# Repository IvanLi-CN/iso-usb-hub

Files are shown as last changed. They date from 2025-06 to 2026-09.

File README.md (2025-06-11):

# Ivan's Isolated USB HUB

3C1A, isolated High Speed USB Hub.

The FreeCAD project file is located at [`models/iso-usb-hub-with-pd.FCStd`](models/iso-usb-hub-with-pd.FCStd).
Exported 3D printable models for the front and back covers are located at:

- [`models/iso-usb-hub-with-pd-Front.step`](models/iso-usb-hub-with-pd-Front.step)
- [`models/iso-usb-hub-with-pd-Back.step`](models/iso-usb-hub-with-pd-Back.step)

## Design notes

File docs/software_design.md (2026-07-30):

# 软件设计文档

本文件为项目的软件设计总文档，收录各子模块的软件规范、调度建议与统一的日志风格。新增或调整任何模块设计，须更新本文件保持单一事实来源。

## 0. 全局约定

### 0.1 全局目标状态

- 定义全局读写锁变量：`PWR_SW_TARGET`，枚举：`Open` / `Closed`。
  - 类型建议（实现细节示例，不具强制性）：`static RwLock<PowerSwitchTarget>`。
  - 语义：目标状态（意图），不等同于实际导通状态。

### 0.2 日志风格

- 统一使用分级日志（`log` → `esp-println`），单行键值对风格，便于机读与筛选。
- 模块前缀使用短名加域，如：`pwr.in`（电源输入）。
- SI 单位与后缀：电压 `V`、电流 `A` 等。
- 级别：
  - 周期/状态与条件变化：`info`；
  - 读数失败：`warn`；
  - 明显非法/越界：`error`。

### 0.3 调度与并发（embassy 建议）

- 使用 `embassy-time` 为周期任务建两个独立异步任务；共享测量数据与目标态使用 `RwLock/Mutex` 保护；
- 避免死锁：按“先读目标态、后读测量”的固定顺序获取锁。

---

## 1. 固件初始化流程（Boot Init）

说明：初始化阶段在主任务启动后、其他周期性任务（如电源输入资格/状态任务）之前一次性执行。I²C 总线为共享资源，初始化流程需串行访问，避免并发访问。

### 1.1 启动阶段与自检状态机

- 启动流程分为 `Early Bring-up -> Self-Check -> Gate Apply -> Runtime` 四阶段，由统一的 boot self-check 快照驱动。
- `Self-Check` 阶段同时承担三件事：
  - 输出 `boot.stage:*`、`boot.check:*`、`boot.summary:*` 日志；
  - 驱动 160x50 LCD 的启动自检页；
  - 产出 `GateDecision`，决定是否放行 runtime task、front panel 和各路端口。
- 统一状态口径：
  - `SelfCheckItemState = Pending / Ok / Warn / Err / Fatal / Skipped`
  - `BootOutcome = Ok / Degraded / Fatal`
  - `BootFaultCode` 覆盖 `MuxOffline`、`PowerInUnavailable`、`PowerInPgBad`、`PowerInOvervoltage`、`InaUnavailable`、`FrontPanelOffline`、`FanUnavailable` 以及按端口编号的配对/保护/超时故障。
- 默认策略是“只读探测 + 分级降级”：
  - 缺模块、单路异常优先降级；
  - 当前 V3 硬件下，front panel 离线在有限恢复失败后降级继续运行；
  - 只有输入电源不安全、或明确无法保证通道安全关闭时才进入 `Fatal`。

### 1.2 基础初始化（时钟/日志/时间源/I²C/LCD）

- 时钟与外设：调用 `esp_hal::init(esp_hal::Config::default())` 初始化外设；用 `esp_hal_embassy::init()` 绑定 `embassy-time` 时间源。
- 日志：沿用“0.2 日志风格（defmt）”；启动关键路径必须保持单行键值对输出，便于错过串口首帧时仍能从后续摘要定位问题。
- I²C：V3 使用两条 MCU I²C 控制器并分别用 `embassy_sync::Mutex` + `static_cell::StaticCell` 构建共享访问。
  - `SDA1/SCL1 = GPIO8/GPIO9`：输入 INA226、前面板、OUT3/OUT4 输出模块传感器；
  - `SDA0/SCL0 = GPIO14/GPIO13`：主板 `TCA6408A@0x20` hub-sideband、OUT1/OUT2 输出模块传感器。
- LCD：显示初始化成功后，先进入 boot self-check 页，不再把 dashboard 首帧当作“系统一定正常”的信号。
  - 当前 V3 主板由 MCU 直接驱动 `DC/MOSI/SCLK/BLK`；
  - LCD `CS/RES` 由前面板 `TCA6408A@0x21` 控制：`P6=CS` 保持输出低，`P5=RES` 启动时低脉冲后释放为输出高；
  - `GPIO13/GPIO14` 是 `SCL0/SDA0`，不得作为 LCD `CS/RST` 使用；
  - GC9D01 驱动实例使用 no-op reset pin，避免把 `GPIO35/RESET#` 误当 LCD reset 再次拉低。

初始化期建议日志（示例）：

- `app.start`
- `init.time: embassy-timer=ok`
- `boot.stage: stage=self-check`

### 1.3 自检顺序与门控顺序（强制）

boot self-check 采用固定顺序，避免不同模块各自抢总线与各说各话：

1) 完成日志、时间源、LCD、两条 I²C 与基础 GPIO 的早期 bring-up；
2) 确认当前 I²C 拓扑：
   - 当前工程验证板为直连共享总线，记录 `boot.check: name=mux state=skip fault=-`；
   - 若后续硬件版本恢复 `PCA9545A`，再切回真实 MUX 探测与门控。
3) 启动并等待基础电源输入资格结果：
   - `INA226` 初始化失败、VIN 不可用或 `PG` 不良都由 `power_in::bootstrap_signal()` 返回；
   - 若输入资格失败，`IN_CE` 必须保持关闭态（GPIO41=high，强制下拉 TPS2490 EN），runtime 与端口初始化均不放行。
4) 在 VIN ready 时探测前面板 `TCA6408A` 与风扇链路：
   - 当前 V3 硬件下，front panel 离线记为 `Warn/FrontPanelOffline`，仅关闭面板功能；
   - 风扇链路初始化失败记为 `Warn/FanUnavailable`，不阻断 dashboard。
5) 仅在 `VIN ready` 时初始化主板 CH335F sideband 与四路端口扫描：
   - 主板 `TCA6408A@0x20` 位于 `SDA0/SCL0`，负责读取 CH335F `PWREN#` 与注入 `OVCUR#`；
   - 若 `TCA6408A@0x20` 离线，runtime 进入 degraded manual mode：owner 显式开启的端口可保持输出，但 `OVCUR#` 注入不可用，控制面必须继续报告 sideband fault；
   - 每路检查 V3 输出模块金手指下挂的 `INA226/TMP112` 是否都可达；
   - 当前验证基线下，通道 4 的正式地址组合为 `INA226(0x43)` + `TMP112(0x4B)`；
   - 单路传感器失败只记录该路 `Err`，不再单独阻断该路 `ENx` 放行。
6) 汇总 `GateDecision`，输出 `boot.summary:*`：
   - `BootOutcome=Fatal`：LCD 常驻自检页；
   - `BootOutcome=Degraded`：短暂展示摘要后进入 dashboard；
   - `BootOutcome=Ok`：直接进入 runtime。

### 1.4 I²C 多路开关 PCA9545A（0x70）

- 当前工程验证板未接入 `PCA9545A`，固件按“直连共享总线”运行，并在启动日志中输出：
  - `i2c.topo: direct shared bus; mux probe skipped`
  - `boot.check: name=mux state=skip fault=-`
- 兼容策略：
  - boot self-check 快照继续保留 `mux` 槽位，用于兼容下个硬件版本恢复 `PCA9545A`；
  - 当前版本 `mux=Skipped` 不参与 fatal/degraded 判定，也不阻断端口扫描；
  - 后续若恢复 `PCA9545A`，应在本节恢复真实探测、故障码与门控要求。

### 1.5 四路输出模块发现与初始化（V3: INA226 + TMP112）

- V3 输出模块的金手指暴露 `SDA/SCL/INT/EN`，模块网表可见两颗 I2C 器件：`INA226` 与 `TMP112`。
- 当前验证基线的正式地址表：
  - 通道 1：`INA226(0x40)` + `TMP112(0x48)`
  - 通道 2：`INA226(0x41)` + `TMP112(0x49)`
  - 通道 3：`INA226(0x42)` + `TMP112(0x4A)`
  - 通道 4：`INA226(0x43)` + `TMP112(0x4B)`
- 总线分配以主板网表为准：通道 1/2 位于 `SDA0/SCL0`，通道 3/4 位于 `SDA1/SCL1`。
- 逐通道初始化策略（串行）：
  1) 在共享 I²C 上对该路地址对执行只读 ACK/寄存器探测；
  2) 两颗都在线则将通道标记为 `Ok`；
  3) 任一探测失败则将通道标记为 `Err`，但不改变“总输入 OK 后统一放行输出”的总门控策略。
- 结果与故障码约定：
  - `INA226 + TMP112` 都成功：端口记为 `Ok`，允许该路 dashboard/runtime 读取；
  - 两者都离线：`Err/PortModuleOffline(ch)`；
  - 仅 `INA226` 离线：`Err/PortInaOffline(ch)`；
  - 仅 `TMP112` 离线：`Err/PortTempOffline(ch)`。
- 安全要求：
  - 单路异常不会阻断其它通道扫描；
  - 只要总输入资格为 `OK` 且主板 CH335F sideband 在线，自检结束后按 CH335F sideband 模式与过流 latch 分别控制 `EN1..EN4`；
  - 单路 `Err` 仅影响诊断与运行期该路测量读取，不再单独关断该路输出。
  - 端口传感器缺失按 degraded 处理，不单独提升整机为 fatal。

### 1.5.1 CH335F sideband 与输出门控

- 主板 `TCA6408A@0x20` 连接 CH335F 的 `PWREN#` 与 `OVCUR#`：
  - I²C 位于 `SDA0/SCL0 = GPIO14/GPIO13`；
  - P0/P2/P4/P6：输入，读取低有效 `PWREN1#..4#`，软件语义 `0=enabled`；
  - P1/P3/P5/P7：`OVCUR1#..4#` 注入，低有效。
- MCU `GPIO21` 读取 ISOUSB211 `V1OK`，用于区分上游隔离侧电源状态：
  - `V1OK=low`：standalone/no-upstream，产品保持独立供电输出能力；
  - `V1OK=high`：upstream-managed，按 CH335F `PWREN#` 控制对应通道。
- 初始化默认释放所有 `OVCUR#`：
  - 输出寄存器 `0x01` 写 `0xFF`；
  - 极性寄存器 `0x02` 写 `0x00`；
  - 配置寄存器 `0x03` 写 `0xFF`，让 `OVCUR#` 处于输入高阻释放状态。
- 运行期每路输出使能条件：
  - `VIN ready`；
  - 主板 `TCA6408A@0x20` 在线；若离线则进入 degraded manual mode，仅按 owner 手动状态与 OCP latch 放行输出；
  - 若 `V1OK=low`，进入 standalone 模式：四路输出不因 `PWREN#` 关闭；
  - 若 `V1OK=high`，进入 upstream-managed 模式：对应 `PWREN#` 为低的通道允许输出，为高的通道关闭输出；
  - 对应软件过流 latch 未置位。
- `OVCUR#` 控制策略：
  - 释放：先写输出位为 `1`，再把对应 P 口配置为输入；
  - 注入过流：先写输出位为 `0`，再把对应 P 口配置为输出。
- 软件过流判定：
  - `vbus < 3.0 V && current > 0.1 A`；
  - 或 `current > 5.3 A`；
  - 命中任一条件立即关闭对应 `ENx` 并注入 `OVCUR#`；
  - 连续 4 个 500 ms 运行期采样周期恢复安全后释放 latch；
  - 关闭输出后采到的 0V/0mA 不作为安全恢复证据；
  - latch 后先关断，再在 sideband 模式、前面板手动状态与全局目标仍允许时进入带电恢复探测，只有带电样本连续安全才释放。

### 1.6 前面板与风扇链路

- 主板 `RESET#` 使用 `GPIO35`，低电平复位主板侧相关器件和前面板 `TCA6408A@0x21`，启动时固件先输出低电平脉冲，再以推挽高电平保持释放，并记录释放电平。
- 前面板 `TCA6408A@0x21` 在线后，固件配置 `P5/P6` 为 LCD `RES/CS` 输出；按键输入使用 `P0..P4`。
- 主板风扇供电由 `TPS62933DRLR` buck 生成 `FAN_VCC`：
  - `GPIO2/FAN_EN` 直接驱动 buck `EN`，高电平使能；
  - `GPIO1/FAN_PWM` 通过 `R15 -> VCTRL/C16 -> R18` 注入 buck `FB`；
  - `FAN_PWM` 平均电压越高，`FB` 越高，`FAN_VCC` 越低，因此固件的速度百分比到硬件 duty 为反相映射；
  - `GPIO6/FAN_TOUCH` 通过 PCNT 计数，外部 4.7 kΩ 上拉到 3V3，并有 100 pF 到地滤波。
- 硬件快照将风扇运行期状态作为调试契约输出：内部温度、过温告警、`FAN_EN` 使能、tach 可信性、实测 RPM、目标 RPM、最大 RPM、控制速度百分比与反相后的硬件 PWM duty。
- 固件初始化 I²C 外设前先释放 SDA/SCL 并输出 SCL 恢复脉冲，清理 MCU-only reset 可能留下的半截 I²C 事务。
- 前面板 `TCA6408A` 地址为 `0x21`，仅在输入电源 ready 后探测。
- 成功日志：`i2c.front: tca6408a=online addr=0x21`
- 失败日志：`i2c.front: tca6408a=offline addr=0x21; retry=N/M`
- 前面板离线诊断日志：
  - `i2c.recover:*` 记录 bus-clear 前后的 SDA/SCL 电平；
  - `i2c.front_probe:*` 记录 `0x21` 输入寄存器读取和 ACK fallback；
  - `i2c.front_diag:*` 记录 `0x21/0x20/0x44/0x70` 在线矩阵和分类。
- 门控要求：
  - 当前 V3 硬件没有 MCU 可控的前面板 TCA reset/VCCP 恢复路径；
  - 固件在初始化 I²C 前执行 bus-clear，随后有限次探测 `0x21`；
  - 若 bus-clear 后共享总线上其它器件在线但 `0x21` 仍不 ACK，当前硬件标记 `Warn/FrontPanelOffline` 并继续 dashboard/runtime，仅禁用前面板输入任务；
  - 未来硬件修订引出前面板 TCA `RESET#` 或 VCCP 控制后，应撤销当前降级路径，改为执行硬复位恢复并要求 `0x21` 在线后再进入 runtime；
  - 风扇链路初始化失败仅记录 `Warn/FanUnavailable`，不将整机提升为 fatal。
- 运行期前面板按键以 `INT` 触发读取为主，低频 fallback 轮询仅用于兜底，避免频繁占用共享 I²C 总线。

### 1.7 启动失败与异常处理约定

- 器件“不可达/不存在”优先记录为 `Warn / Err / Skipped`，不允许直接因为单个探测失败而 `panic!`；
- 输入电源资格失败时：
  - `IN_CE` 必须保持关闭态（GPIO41=high，强制下拉 TPS2490 EN）；
  - 四路端口全部 `Skipped`；
  - `GateDecision.allow_runtime_tasks=false`；
  - LCD 停留在 fatal 自检页。
  - 若 `INA226.VBUS > 28.0 V`，故障码为 `PowerInOvervoltage`，串口、LCD 与硬件快照显示 `VIN OVP`。
- 通道传感器缺失（`INA226/TMP112` 不齐）：
  - 打印 `warn`；
  - 标记对应通道 `Err`；
  - 继续扫描其它通道，并在总输入 `OK` 时保持统一放行输出。
- 统一摘要日志示例：
  - `boot.check: name=vin state=FATAL fault=PG BAD ...`
  - `boot.summary: outcome=DEG first_fault=FAN runtime=on front_panel=on`

### 1.8 运行期资源交接

- 运行期继续复用共享 async I²C；
- 只有 `GateDecision.allow_runtime_tasks=true` 时，才允许进入 dashboard 与周期刷新；
- 只有 `GateDecision.allow_front_panel=true` 时，才允许启动前面板任务；
- `BootSelfCheckSnapshot` 是日志、自检页与门控决策的单一事实来源。

### 1.8.1 前面板手动通道控制

- 前面板任务只负责读取 TCA6408A 输入并发布去抖后的按键下降沿事件，不直接持有或驱动 `EN1..EN4`。
- Dashboard 运行期维护当前选中通道，初始为通道 1；左/右方向键在 4 路输出间循环移动选中通道。
- 中键短按切换选中通道的手动输出允许状态：
  - 手动断开时，对应 `ENx` 拉低，dashboard 该列显示 `OFF`；
  - 手动恢复时，仅当总输入资格仍为 ready 时，对应 `ENx` 拉高；
  - 手动断开状态优先于 INA226/TMP112 在线状态和运行期遥测显示。
- 左/右选择变化与中键手动状态变化必须立即触发当前 dashboard 帧重绘并刷新到 LCD；周期遥测刷新不能成为前面板交互反馈的唯一显示路径。
- 手动状态不持久化；每次上电后默认四路手动允许，实际输出仍受总输入电源门控约束。

### 1.8.2 蜂鸣器音效

- V3 `BUZZER` 网络由 ESP32-S3 `GPIO7` 驱动；固件使用 LEDC 硬件 PWM 播放无源蜂鸣器音效。LEDC 外设由启动流程统一初始化，fan 使用 Timer0/Channel0，蜂鸣器使用 Timer1/Channel1，播放期间 CPU 只在音符边界调度，不生成半周期波形。
- GPIO7 空闲与每段音效播放完成后必须拉低，确保静音态稳定。
- 硬件快照输出蜂鸣器 driver ready、当前是否播放、one-shot tone、循环 alarm、频率与 duty，用于只读调试，不提供写寄存器或强制发声入口。
- 固件内置音效表来自 `tools/buzzer_audio_preview/` 试听页的推荐候选；运行时不读取 HTML、JSON、MIDI 或 WAV 试听产物。
- Boot 音：
  - boot self-check 结果非 `Fatal`，且阶段切换到 `Runtime` 后播放开机音；
  - `Fatal` 停留页不播放开机音。
- 前面板按键音：
  - Left/Right 选中通道移动成功时播放操作提示音；
  - Center 成功启用通道时播放通道上电音；
  - Center 成功禁用通道时播放通道断电音；
  - Center 尝试启用通道但因 OCP latch、全局 `PWR_SW_TARGET=Open`、CH335F sideband gate 或端口未就绪被拒绝时播放操作拒绝音，并记录拒绝原因；
  - Up/Down 当前无定义动作，保持静默。
- USB JSONL 与 network 控制面触发 `PortPowerSet(enabled=true)` 时播放通道上电音；触发 `PortPowerSet(enabled=false)` 或 `PortReplug` 时播放通道断电音。
- 告警音由运行期 reducer 选择唯一 active alarm，优先级为：
  1. `channel_short`；
  2. `over_temp`；
  3. `input_over_power`；
  4. `channel_over_5a`；
  5. one-shot 音效。
- 告警映射：
  - `channel_short` 复用现有低 VBUS OCP：`vbus < 3000mV && current > 100mA`；
  - `channel_over_5a` 在任一 active 通道的新鲜遥测 `current_ma >= 5000` 或 high-current OCP latch 时触发，按长间隔循环；
  - `over_temp` 复用 fan 安全阈值：80C 触发，75C 清除；
  - `input_over_power` 使用输入电源最新状态计算 `VIN * |I|`：100W 触发，90W 清除。
- 通道提示音使用 per-port hysteresis：
  - 插入：`vbus_mv >= 3300`；
  - 拔出：`vbus_mv < 3000`；
  - 3A 提示：首次 `current_ma >= 3000`，低于 `2800` 后复位；
  - 5A 提示：首次 `current_ma >= 5000`，低于 `4800` 后复位。
- 保护关断同一 tick 内必须抑制普通拔出/断电提示，只保留告警音。
- 可观测日志：
  - `buzzer.play: tone=<name>`；
  - `buzzer.alarm: active=<name|none>`；
  - `buzzer.alarm.play: tone=<name>`。

### 1.8.3 只读硬件底层快照

- 固件通过 Local USB JSONL `hardware.snapshot` 返回最新 `isolarail.hardware.snapshot.v1` 快照缓存；
- 快照是只读诊断接口，只汇总已有启动自检、运行期采样、I²C 探测和寄存器只读结果；
- 节点状态统一使用 `online` / `offline` / `skipped` / `error`，前面板 `TCA6408A@0x21` 与四路输出模块传感器允许离线；
- 单个节点离线只进入该节点状态与 reason，不得导致整包输出失败；
- Web 高级调试页位于 `/devices/:deviceId/debug/hardware`，作为设备路径下的 Advanced/Debug 入口，不替代主 dashboard/settings workflow；
- 详细 schema 与验收标准见 `docs/specs/n8x4q-hardware-diag-snapshot/SPEC.md`。

### 1.9 参考 crate 与接口（事实依据）

- PCA9545A：未来恢复该硬件版本时再接回 `xca9548a` / 等价驱动；当前直连共享总线版本未启用。
- TCA6408A：`port-expander`（`Tca6408a`，基于 embedded‑hal v1，阻塞接口）。
- INA226：`ina226-tp`（async 驱动，既用于输入电源链路，也用于 V3 输出模块运行期读数）。

以上 crate 均可通过 GitHub/Docs.rs 查验 API 与用法；若后续替换为 crates.io 正式版本，请在 `Cargo.toml` 中同步更新来源与版本并在变更说明中登记。

---

## 2. 基础电源输入子系统

本节定义基础电源输入子系统的软件行为、数据源、周期性任务、判定逻辑与日志格式，确保行为可重复且无二义性。

### 2.1 硬件与信号约定

- `INA226`（I2C）：读取输入母线电压/电流。
  - 电压：`VBUS`（单位：V）。
  - 电流：`CURRENT` 或由分流电阻计算（单位：A）。
- `VIN_ADC`（ESP32-S3 `GPIO4 / ADC1_CH3`）：输入电压分压采样。
  - 分压比：11:1（100kΩ+10kΩ），母线电压换算：`V_in_from_adc = VIN_ADC * 11`。
- `IN_PG`（ESP32-S3 `GPIO42`，源自 TPS2490 `PG` 引脚）：
  - 极性：高电平表示 Power-Good（良好），低电平表示非良好/故障；
  - 类型：开漏输出（需上拉）；
  - 依据：TI TPS2490 数据手册（Power Good Open-Drain Output）。
- `IN_CE`（ESP32-S3 `GPIO41`）：驱动一颗 NMOS 下拉 TPS2490 `EN`。
  - GPIO41 高：NMOS 导通，TPS2490 `EN` 被下拉，输入开关强制关闭；
  - GPIO41 低：NMOS 关断，TPS2490 `EN` 由外围网络决定，允许输入开关闭合。

### 2.2 判定与周期任务

#### 2.2.1 启动期资格判定（基于 INA226）

> 开发阶段特别说明（当前分支生效）：
>
> - 为便于在实验室以 5V 台式电源/USB 供电对风扇等功能做独立验证，固件将 VIN 下限阈值临时放宽为 **4.5 V**（`VIN_MIN_V=4.5`）。
> - 该设置会绕过原本的欠压防护，可能导致在 5–8 V 区间触发上电流程。仅限开发/联调使用，量产前请恢复到 **9.0 V** 并完成回归验证。

- 触发条件：上电启动阶段、闭合输入开关之前执行，短暂重试（~5 次，20 ms 间隔）。
- 计算：
  - 生产阈值（规范）：`9.0 V ≤ INA226.VBUS ≤ 28.0 V`；
  - 当前固件（开发分支）：`4.5 V ≤ INA226.VBUS ≤ 28.0 V`；
- `current_ok`：`|INA226.CURRENT| ≤ 30 mA`；
  - `ok_to_close = range_ok && current_ok`。
- 日志：每次读取打印一行 `info`：`pwr.in:qual vbus=..V i=..A range_ok= current_ok=`。
- 成功后：拉低 `IN_CE` 允许输入开关闭合，并将本次 `VBUS/CURRENT` 写入共享测量，避免状态上报出现 `vin=n/a`。
- `VIN_ADC` 不参与资格判定；仅在 `PG` 超时（100 ms）时单次读取用于诊断。

#### 2.2.2 10 s 状态汇报

- 周期：`10 s`，无条件输出一行状态：
  - 字段：
    - `vin`（INA226.VBUS, V）
    - `i`（INA226.CURRENT, A）
    - `sw_intent`（on/off，来自 `PWR_SW_TARGET`，表示期望状态）
    - `sw_actual`（on/off，由 `IN_PG` 推导：PG=good→on，PG=bad→off）
    - `pg`（good/bad，由 IN_PG）
    - `note`（可空）
- 判定：
  - `pg`：IN_PG 高为 `good`，低为 `bad`；
  - 异常：若 `PWR_SW_TARGET == Closed` 且 `pg == good`，但 `V_in_from_adc` 明显低于 `INA226.VBUS`，追加 `note` 告警：
    - 比值阈值：`V_in_from_adc / INA226.VBUS < 0.60`；
    - 或差值阈值：`INA226.VBUS - V_in_from_adc > 3.0 V`；
    - 示例：`note="anom: vin_adc<<ina_v (adc=4.2V, ina=12.1V)"`。
- 示例：`pwr.in:stat vin=12.1V i=0.46A sw_intent=on sw_actual=on pg=good`。

### 2.3 边界与错误处理

- `INA226`/`VIN_ADC` 读数失败：本周期忽略数值、输出一次 `warn`，维持上次有效判定；
- 越界保护：启动资格及每个 `100 ms` 运行期保护采样中，若 `INA226.VBUS > 28.0 V`，视为输入过压，在下一保护采样周期内保持输入开关关闭并报告 `VIN OVP`；运行期过压会锁存输入关闭，直至重启或显式恢复策略。

### 2.4 精度与阈值

- 生产电压范围阈值：9.0 V 与 28.0 V；
- 开发阶段（当前分支）临时阈值：`VIN_MIN_V = 4.5 V`（为 5V 台架测试放宽）；
- 当前 V3 板启动资格电流阈值：`I_IDLE_MAX_A = 30 mA`；
  - 依据：当前 V3 基线板在 `IN_EN` 闭合前的实测空载电流约为 `22–23 mA`；
  - 旧的 `10 mA` 假设会把当前板误判成 `VIN OFF/FATAL`，导致 runtime 和 USB JSONL 永远不启动；
  - `VIN_ADC` 判定阈值固定为 2.0 V（ADC 端）；
  - 异常比值/差值阈值如上；修改阈值须同步更新本文档。

### 2.5 调度与并发（实现建议）

- `InputQualificationTask`（100 ms）与 `InputStatusTask`（10 s）两个异步任务；
- 数据共享用 `RwLock/Mutex`；获取顺序：目标态 → 测量值。

### 2.6 观测与验证要点

- 目标从 `Open→Closed` 且电压合规、`VIN_ADC < 2.0 V`，应出现一次 `ok_to_close=true` 的变化日志；
- 正常供电下，每 10 s 一行状态，`pg=good`、`ocp=false`；
- 保护/异常时，`pg=bad` 或 `note` 告警出现。

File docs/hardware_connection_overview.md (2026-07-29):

# 硬件连接概览（IsolaRail V3）

本文件汇总当前 `isolarail` V3 基线板的关键硬件连接关系，作为 README、控制面 spec 与软件设计文档之间共享的 current truth。owner-facing 设备模型固定为四路 `port1..port4`；历史 V2 `SC8815 + SW2303` / `PSTOP*` 方案不再作为本文件事实源。

## 适用范围

- 当前软件落地基线：`ESP32-S3 + CH335F + M24C64@0x50 + EN1..EN4 + PWREN#/OVCUR# + 160x50 LCD + front panel`
- 端口模型：`Port 1`、`Port 2`、`Port 3`、`Port 4`
- 当前控制面维护动作：
  - `port.replug` = 受控断电再上电
  - `hub.reset` = 整机维护复位动作

## 总体结构

- 主控：`ESP32-S3`
- USB Hub 控制器：`CH335F`
- Wi-Fi / 网络配置 EEPROM：`M24C64@0x50`
- 输入电源热插拔 / 保护：`TPS2490`
- 输入电源监测：`Input INA226@0x44`
- 主板 sideband expander：`Mainboard TCA6408A@0x20`
- 前面板 / LCD 控制 expander：`Front-panel TCA6408A@0x21`
- 预留 / 兼容命名槽位：`PCA9545A@0x70`

## 电源输入（VIN_UNSAFE → VIN）

- 直流输入网络名：`VIN_UNSAFE`
- 主系统母线：`VIN`
- 输入路径：`VIN_UNSAFE -> 5 mΩ shunt -> TPS2490 / 输入开关 -> VIN`
- 整机额定输入电压上限：`28 V`；输入 TVS 必须安装反向截止电压为 `28–30 V` 的器件。
- 关键控制/观测网络：
  - `IN_EN`：MCU 控制输入开关资格
  - `IN_PG`：高电平表示 power-good
  - `VIN_ADC`：MCU ADC 分压采样点
- 输入电源测量器件：
  - `Input INA226@0x44`：输入电压 / 电流 / 功率观测

## 四路输出与端口门控

- 四路 owner-facing 端口由 `EN1..EN4` 门控：
  - `EN1 -> Port 1`
  - `EN2 -> Port 2`
  - `EN3 -> Port 3`
  - `EN4 -> Port 4`
- 当前实现里 MCU 直驱的四路 enable GPIO 为：
  - `EN1 = GPIO17`
  - `EN2 = GPIO18`
  - `EN3 = GPIO39`
  - `EN4 = GPIO40`
- 当前 V3 板的软件语义：
  - `port.power_set` 直接影响对应 `ENx`
  - `port.replug` 通过临时拉低再恢复对应 `ENx` 实现
  - 不承诺真 per-port data disconnect

## CH335F sideband 与上游联动

- `CH335F` 的 sideband 通过 `Mainboard TCA6408A@0x20` 连接到 MCU
- 低有效输入：
  - `PWREN1#`
  - `PWREN2#`
  - `PWREN3#`
  - `PWREN4#`
- 低有效注入：
  - `OVCUR1#`
  - `OVCUR2#`
  - `OVCUR3#`
  - `OVCUR4#`
- 上游隔离状态：
  - `ISOUSB211 V1OK` 为 owner-facing 运行时状态
  - 板级网络名：`ISO_OK`
- `V1OK=low` 时，设备按 standalone/no-upstream 处理
- `V1OK=high` 时，设备按 upstream-managed 模式读取 `PWREN#`

## 两条 I²C 总线

### Sensor / front-panel I²C

- `I2C_SDA = GPIO8`
- `I2C_SCL = GPIO9`
- 当前挂载：
  - `Input INA226@0x44`
  - `Front-panel TCA6408A@0x21`
  - `Port 3 INA226@0x42 + TMP112@0x4A`
  - `Port 4 INA226@0x43 + TMP112@0x4B`

### Hub-sideband / output I²C

- `HUB_SDA = GPIO14`
- `HUB_SCL = GPIO13`
- 当前挂载：
  - `Mainboard TCA6408A@0x20`
  - `Port 1 INA226@0x40 + TMP112@0x48`
  - `Port 2 INA226@0x41 + TMP112@0x49`
  - `M24C64@0x50`

## EEPROM 与 Wi-Fi provisioning

- 配置 EEPROM：`M24C64@0x50`
- 当前固件通过板级路由信号访问该 EEPROM：
  - `ROM_WC = GPIO37`，运行期保持 low 允许写入
  - `ROM_ROUTE = GPIO38`，当前固件设为 high 选择 firmware/EERPOM 路径
- 用途：
  - 保存 Wi-Fi SSID / PSK 与网络配置
  - 作为 USB / LAN / companion / web 统一消费的设备持久化入口

## 每路端口遥测地址

- `Port 1`：`INA226@0x40` + `TMP112@0x48`
- `Port 2`：`INA226@0x41` + `TMP112@0x49`
- `Port 3`：`INA226@0x42` + `TMP112@0x4A`
- `Port 4`：`INA226@0x43` + `TMP112@0x4B`

这些地址用于运行期电压/电流/功率/温度观测，不改变 owner-facing 四路端口语义。

## 前面板与显示

- 前面板 expander：`Front-panel TCA6408A@0x21`
- 五向开关：
  - `P0 = Center`
  - `P1 = Right`
  - `P2 = Down`
  - `P3 = Left`
  - `P4 = Up`
- LCD 控制：
  - `P5 = LCD_RES`
  - `P6 = LCD_CS`
- LCD 直连 MCU 的 SPI / 控制网络：
  - `LCD_DC = GPIO10`
  - `LCD_MOSI = GPIO11`
  - `LCD_SCLK = GPIO12`
  - `LCD_BLK = GPIO15`
- 显示模块：`160x50 LCD`
- 驱动 IC：`GC9D01`
- 背光 `LCD_BLK` 当前为低有效

## Reset / 中断 / 其他板级网络

- `Mainboard RESET# = GPIO35`
- `I2C_INT`：共享 I²C 外设中断汇总输入
- `HUB_RESET#`：CH335F 复位控制网络
- `USB D+` / `USB D-`：ESP32-S3 原生 USB 差分对
- `BUZZER`：蜂鸣器控制网络
- `FAN_PWM` / `FAN_EN` / `FAN_TACH`：风扇控制与反馈网络

## 当前 V3 与历史 V2 的边界

- 本文件只描述当前 V3 current truth
- 下列术语只允许出现在历史/迁移语境，不再代表当前控制面硬件：
  - `SC8815 + SW2303`
  - `PSTOP_CTL1..4`
  - `PSTOP1..4`
  - 历史 `USB-C route` / 双口产品抽象
- `PCA9545A@0x70` 在当前文档中只作为兼容命名槽位保留；当前软件运行基线不是依赖它完成端口寻址

## 简化拓扑示意

```text
DC IN
  └─ VIN_UNSAFE -> shunt -> TPS2490 / input gate -> VIN
                      └─ Input INA226@0x44

ESP32-S3
  ├─ Sensor I2C (GPIO8/GPIO9)
  │   ├─ Front-panel TCA6408A@0x21
  │   ├─ Input INA226@0x44
  │   ├─ Port 3 INA226@0x42 + TMP112@0x4A
  │   └─ Port 4 INA226@0x43 + TMP112@0x4B
  ├─ Hub I2C (GPIO14/GPIO13)
  │   ├─ Mainboard TCA6408A@0x20
  │   ├─ M24C64@0x50
  │   ├─ Port 1 INA226@0x40 + TMP112@0x48
  │   └─ Port 2 INA226@0x41 + TMP112@0x49
  ├─ EN1..EN4 -> Port 1..4 power gate
  ├─ ISO_OK / V1OK <- upstream isolation status
  ├─ USB D+ / D- <-> native USB
  └─ LCD + front panel + buzzer + fan

CH335F
  ├─ PWREN1#..4# -> Mainboard TCA6408A@0x20 -> MCU
  └─ OVCUR1#..4# <- Mainboard TCA6408A@0x20 <- MCU
```

## 参考

- `docs/specs/pw97u-control-plane-alignment/SPEC.md`
- `docs/specs/j6nvw-hardware-v3-pin-assignment/SPEC.md`
- `docs/software_design.md`

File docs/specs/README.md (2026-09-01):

# 规格（Spec）总览

本目录用于管理工作项的**规格与追踪**：记录范围、验收标准、任务清单与状态，作为交付依据；实现与验证应以对应 `SPEC.md` 为准。

当前仓库的软件与硬件命名真相源由 `pw97u-control-plane-alignment/SPEC.md` 统一定义：

- 固件 package / identity：`isolarail`
- repo JS tooling package：`isolarail-dev-tools`
- CLI：`isolarail`
- daemon：`isolarail-devd`
- companion workspace：`tools/isolarail-companion/`
- internal support crates / tools：`gc9d01`、`dashboard_preview`、`icon2raw`、`png2raw`
- vendored example packages：`gc9d01/examples/**` 下的示例包名仅用于驱动示例，不得进入本项目 owner-facing 命名
- 开发者入口：`just`
- owner-facing 端口模型：`port1..port4`
- 当前硬件基线：`V3`
- 主控与关键子系统名：`ESP32-S3`、`CH335F`、`M24C64@0x50`、`TPS2490`、`ISOUSB211 V1OK`、`PCA9545A@0x70`、`Mainboard TCA6408A@0x20`、`Front-panel TCA6408A@0x21`
- legacy/scoped hardware names：`SC8815 + SW2303`、`PSTOP_CTL/PSTOP`、`VIN_ADC`、`PCA9545A INT/INTx`、scoped `RESET#` 只允许在硬件拓扑或迁移语境下出现
- 参考硬件资料中的 `TPS82130SILR`、`RT9043GB`、`TCA6408APWR`、`TCA6408ARSVR`、`TCA9535RTWR` 等料号仅允许作为 reference-only 历史输入，不得覆盖当前 V3 控制面命名

后续 spec、README、实现与 UI 文案不得偏离这套命名；BOM/netlist 精确料号只能作为电气资料别名，不能替代控制面 canonical 名称。

> Legacy compatibility: historical repos may still contain `docs/plan/**/PLAN.md`. New entries must be created under `docs/specs/**/SPEC.md`.

## 快速新增一个规格

1. 生成一个新的规格 `ID`（推荐 5 个字符的 nanoId 风格，降低并行建规格时的冲突概率）。
2. 新建目录：`docs/specs/<id>-<title>/`（`<title>` 用简短 slug，建议 kebab-case）。
3. 在该目录下创建 `SPEC.md`（模板见下方“SPEC.md 写法（简要）”）。
4. 在下方 Index 表新增一行，并把 `Status` 设为 `待设计` 或 `待实现`（取决于是否已冻结验收标准），并填入 `Last`（通常为当天）。

## 目录与命名规则

- 每个规格一个目录：`docs/specs/<id>-<title>/`
- `<id>`：推荐 5 个字符的 nanoId 风格，一经分配不要变更。
  - 推荐字符集（小写 + 避免易混淆字符）：`23456789abcdefghjkmnpqrstuvwxyz`
  - 正则：`[23456789abcdefghjkmnpqrstuvwxyz]{5}`
  - 兼容：若仓库历史已使用四位数字 `0001`-`9999`，允许继续共存。
- `<title>`：短标题 slug（建议 kebab-case，避免空格与特殊字符）；目录名尽量稳定。
- 人类可读标题写在 Index 的 `Title` 列；标题变更优先改 `Title`，不强制改目录名。

## 状态（Status）说明

仅允许使用以下状态值：

- `待设计`：范围/约束/验收标准尚未冻结，仍在补齐信息与决策。
- `待实现`：规格已冻结，可开工；实现与测试验证应以该规格为准。
- `跳过`：计划已冻结或部分完成，但**当前明确不应自动开工**（例如需要特定时机/外部条件/等待依赖）；自动挑选“下一个规格”时应跳过它。需要实现时再把状态改回 `待实现`（或由主人显式点名实现该规格）。
- `部分完成（x/y）`：实现进行中；`y` 为该规格里定义的“实现里程碑”数，`x` 为已完成“实现里程碑”数（见该规格 `SPEC.md` 的 Milestones；不要把计划阶段产出算进里程碑）。
- `已完成`：该规格已完成（实现已落地或将随某个 PR 落地）；如需关联 PR 号，写在 Index 的 `Notes`（例如 `PR #123`）。
- `作废`：不再推进（取消/价值不足/外部条件变化）。
- `重新设计（#<id>）`：该规格被另一个规格取代；`#<id>` 指向新的规格编号。

## `Last` 字段约定（推进时间）

- `Last` 表示该规格**上一次“推进进度/口径”**的日期，用于快速发现长期未推进的规格。
- 仅在以下情况更新 `Last`（不要因为改措辞/排版就更新）：
  - `Status` 变化（例如 `待设计` -> `待实现`，或 `部分完成（x/y）` -> `已完成`）
  - `Notes` 中写入/更新 PR 号（例如 `PR #123`）
  - `SPEC.md` 的里程碑勾选变化
  - 范围/验收标准冻结或发生实质变更

## SPEC.md 写法（简要）

每个规格的 `SPEC.md` 至少应包含：

- 背景/问题陈述（为什么要做）
- 目标 / 非目标（做什么、不做什么）
- 范围（in/out）
- 需求列表（MUST/SHOULD/COULD）
- 功能与行为规格（Functional/Behavior Spec：核心流程/关键边界/错误反馈）
- 验收标准（Given/When/Then + 边界/异常）
- 实现前置条件（Definition of Ready / Preconditions；未满足则保持 `待设计`）
- 非功能性验收/质量门槛（测试策略、质量检查、Storybook/视觉回归等按仓库已有约定）
- 文档更新（需要同步更新的项目设计文档/架构说明/README/ADR）
- 实现里程碑（Milestones，用于驱动 `部分完成（x/y）`；只写实现交付物，不要包含计划阶段产出）
- 风险与开放问题（需要决策的点）
- 假设（需主人确认）

## Index（固定表格）

<!-- markdownlint-disable MD060 -->
| ID | Title | Status | Spec | Last | Notes  |
|---:|---|---|---|---|---|
| k3p8m | 示例：新增工作项规格 | 待设计 | `k3p8m-example-spec/SPEC.md` | YYYY-MM-DD | - |
| pw97u | 四路 USB Hub 控制面对齐 | 已完成 | `pw97u-control-plane-alignment/SPEC.md` | 2026-06-29 | 当前 HEAD 已完成本地 `PR-ready` 收口：Wi-Fi/LAN、USB CDC、companion、web、current-truth 文档与视觉证据已统一对齐 |
| 5f74j | 固件健壮化与开机自检 | 已完成 | `5f74j-firmware-boot-self-check/SPEC.md` | 2026-03-17 | 当前板型为直连 I2C；保留 mux 槽位以兼容后续 PCA9545A |
| j6nvw | 硬件 V3 引脚与显示链路对齐 | 部分完成（2/3） | `j6nvw-hardware-v3-pin-assignment/SPEC.md` | 2026-04-27 | legacy `docs/plan/j6nvw-hw-v3-pin-assignment/**` 删除待确认 |
| h8c4s | CH335F sideband 电源控制 | 部分完成（2/3） | `h8c4s-ch335f-sideband-power-control/SPEC.md` | 2026-06-13 | 固件与上游侧 p1/p3/p4 控制已验证；命名已对齐到 `isolarail` / 上游侧语义；PWREN1#/2# 硬件缺陷见 issue #18 |
| 7gf6b | 固件蜂鸣器音效 | 已完成 | `7gf6b-firmware-buzzer-audio/SPEC.md` | 2026-07-05 | PR #25 |
| e5nyr | 发布失败 Telegram 告警接入 | 已完成 | `e5nyr-release-failure-telegram-alerts/SPEC.md` | 2026-09-01 | 发布/部署失败与手动 smoke 已迁移到 Oidrune `notify.yml@e48822f99c6402a753ed86557ea029754cbab20b`；GitHub Pages settings 仍需 owner 侧启用 Actions source |
| q9d7h | CLI/devd 烧录迁移 | 部分完成（3/4） | `q9d7h-cli-devd-flash-migration/SPEC.md` | 2026-07-04 | source workflow 已完成，旧烧录入口已退役；真机 flash-monitor 验证待硬件确认 |
| r6wfr | 文档 Web 站点 | 已实现 / 待外部切流 | `r6wfr-docs-site/SPEC.md` | 2026-07-05 | Rspress/Bun 双语 docs-site，`web/` 根站点 + `/docs/` 子站点组合发布到 EdgeOne / GitHub Pages |
| n8x4q | 硬件底层详细信息快照接口 | 部分完成（4/5） | `n8x4q-hardware-diag-snapshot/SPEC.md` | 2026-07-05 | 真机串口端到端验证待硬件接入 |
| b8r3n | 品牌视觉资产 | 已完成 | `b8r3n-brand-visual-assets/SPEC.md` | 2026-07-08 | PR #32；Logo、App Icon、海报、GitHub Social preview 主图与变体、HTML 海报素材 |
<!-- markdownlint-enable MD060 -->

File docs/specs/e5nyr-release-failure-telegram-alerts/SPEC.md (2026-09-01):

# 发布失败 Telegram 告警接入

## Context and Scope

仓库通过 `.github/workflows/notify-release-failure.yml` 为 `Release`、`Development Release` 与 `Site Publish` 提供发布/部署失败告警，并保留 repo-local 的手动 smoke test 入口。

本主题只定义 notifier sidecar 与 Oidrune reusable workflow 的调用契约，不改动发布逻辑、版本策略或产物内容，也不新增第二套通知渠道。调用目标固定为 `IvanLi-CN/oidrune/.github/workflows/notify.yml@e48822f99c6402a753ed86557ea029754cbab20b`，由调用方提供 OIDC 权限和完整 summary。

失败通知覆盖 `Release`、`Development Release` 以及非 PR 的 `Site Publish`；普通 PR CI 不在通知范围内。手动 `workflow_dispatch` 仅用于发送 smoke summary，本地与 PR 验证不得触发真实通知。

## Requirements

### REQ-E5NYR-001: Failure event scope

The notifier MUST listen for completed `Release`, `Development Release`, and `Site Publish` workflow runs, and MUST notify only when the conclusion is `failure`. It MUST exclude `Site Publish` runs whose event is `pull_request`.

### REQ-E5NYR-002: Pinned Oidrune target

Both notification jobs MUST call `IvanLi-CN/oidrune/.github/workflows/notify.yml@e48822f99c6402a753ed86557ea029754cbab20b`. No reusable workflow call may use `@main`.

### REQ-E5NYR-003: OIDC permission

The caller MUST provide `id-token: write` permission to the reusable workflow jobs.

### REQ-E5NYR-004: Default gateway boundary

The caller MUST omit `gateway_url` and `oidc_audience` so the pinned Oidrune workflow uses its default gateway and audience. The caller MUST NOT pass the legacy `SHOUTRRR_URL` secret or any other Telegram secret.

### REQ-E5NYR-005: Complete failure summary

The failure path MUST pass `outcome: failure` and a caller-generated summary containing a failure title, project name, status/result, target SHA, run URL, workflow, ref, attempt, actor, and event. `Site Publish` failures MUST retain deployment-specific title and note semantics.

### REQ-E5NYR-006: Manual smoke path

The `workflow_dispatch` path MUST run only the smoke job and MUST pass `outcome: failure` with a caller-generated summary titled `IsolaRail notifier smoke test`. The summary MUST include the project name, smoke status/result, current SHA, run URL, workflow, ref, attempt, actor, and event.

### REQ-E5NYR-007: Contract coverage

The repository MUST provide a repeatable workflow contract test covering the pinned target, legacy target/secret removal, OIDC permission, summary fields, failure filter, ordinary PR exclusion, and manual smoke path.

## Verification

### VER-E5NYR-001: Static workflow contract

- Method: `actionlint` and the workflow contract test cover: `REQ-E5NYR-001`, `REQ-E5NYR-002`, `REQ-E5NYR-003`, `REQ-E5NYR-004`, `REQ-E5NYR-005`, `REQ-E5NYR-006`, `REQ-E5NYR-007`.

### VER-E5NYR-002: Documentation contract

- Method: the shared Spec drift gate and markdownlint cover: `REQ-E5NYR-002`, `REQ-E5NYR-003`, `REQ-E5NYR-004`, `REQ-E5NYR-005`, `REQ-E5NYR-006`.

### VER-E5NYR-003: Repository validation

- Method: repository `cargo check` and `cargo build --release` cover: `REQ-E5NYR-001`, `REQ-E5NYR-007`.

### VER-E5NYR-004: Delivery safety

- Method: PR CI freshness and manual inspection confirm that no `workflow_dispatch` smoke run, real Telegram/Oidrune notification, or Oidrune control-plane change is performed during migration; covers: `REQ-E5NYR-004`, `REQ-E5NYR-006`.

## Related ADRs

None

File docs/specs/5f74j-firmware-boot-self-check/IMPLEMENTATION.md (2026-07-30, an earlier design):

# 固件健壮化与开机自检实现状态

## 当前状态

- Boot self-check 状态模型、阶段日志、LCD 自检页和 runtime 门控已经落地。
- 当前直连 I2C 板型保留 `mux` 槽位，但不再依赖 `PCA9545A`。
- 输入电源不安全仍是 fatal；单路端口传感器异常按 degraded 记录。
- 输入资格上限为 `28.0 V`；高于上限的输入以 `PowerInOvervoltage` / `VIN OVP` 作为可见 fatal 诊断。运行期每 `100 ms` 采样到过压时，输入开关关闭会锁存，并同步发布 `vin_on=false`。
- 当前 V3 硬件下，前面板 `TCA6408A@0x21` 离线会在有限恢复失败后降级继续运行，仅禁用前面板按键任务。
- 前面板离线时，启动日志会输出 I2C bus-clear 电平、`0x21` 分阶段探测、peer device 在线矩阵和故障分类，便于区分 MCU-only reset 后的 TCA 未复位、总线卡住和共享供电/I2C 异常。

## Coverage

- 固件：`src/main.rs` boot self-check flow、gate decision、front-panel degraded path。
- 固件：`src/boot_diag.rs` 自检状态、故障码与快照模型。
- 固件：`src/power_in.rs` 输入电源启动探测。
- 固件：`src/power_limits.rs` 输入电压范围判定与主机回归测试。
- 文档：`docs/software_design.md` 与本 spec 记录当前启动口径。

## Remaining Gaps

- 当前 V3 前面板 TCA 无 MCU 可控 `RESET#` 或 VCCP power-cycle，固件无法在 MCU-only reset 后硬复位该器件。
- 真机 MCU reset 复现中，SDA/SCL 恢复后均为 high，主板 TCA `0x20` 与输入 INA226 `0x44` 在线，前面板 TCA `0x21` 连续 NACK；当前诊断分类为 `front_tca_only_offline`。
- 未来硬件修订提供前面板 TCA reset/power-cycle 后，应移除 `blocked_no_reset_pin` 降级路径，并重新要求前面板在线后进入 runtime。

## Related Changes

- `src/main.rs`
- `src/front_panel.rs`
- `src/boot_diag.rs`
- `src/power_in.rs`
- `docs/software_design.md`

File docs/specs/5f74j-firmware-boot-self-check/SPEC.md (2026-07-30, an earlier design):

# 固件健壮化与开机自检（#5f74j）

## 状态

- Status: 已完成
- Created: 2026-03-14
- Last: 2026-03-17

## 背景 / 问题陈述

- 当前固件在关键启动探测失败时会直接 `panic!`，例如 `PCA9545A` 不在线时会在启动早期崩溃，导致后续诊断信息丢失。
- 项目需要像 `mains-aegis` 一样，把启动失败转化为可见、可定位、可门控的自检结果，而不是“黑屏 + 无日志”。
- 不做本改造的代价是：真机联调时缺少稳定的故障定位界面，串口监视窗口稍晚接入就会丢掉启动瞬间证据。

## 目标 / 非目标

### Goals

- 将启动过程重构为 `Early Bring-up -> Self-Check -> Gate Apply -> Runtime` 四阶段。
- 引入统一的 boot self-check 状态模型、故障码、门控决策和摘要页口径。
- 缺模块时优先降级继续运行；只有输入电源不安全、无法保证端口关闭、或明确保护粘滞时才进入 fatal 停留态。
- 在 160x50 LCD 上显示最小自检摘要页，并在 degraded/fatal 场景保留可复查的结果。

### Non-goals

- 不实现 `mains-aegis` 的多页面自检 UI、音频 cue、BMS 交互或复杂激活流程。
- 不改硬件地址、原理图、本机联调侧 `isolarail` monitor 产品化体验。

## 范围（Scope）

### In scope

- `src/main.rs` 启动状态机、boot self-check UI、自检日志前缀、门控策略。
- `src/power_in.rs` 启动电源探测改成“上报结果而不是 panic”。
- `src/boot_diag.rs` 新增统一状态模型。
- `docs/software_design.md` 同步新的开机自检与降级口径。

### Out of scope

- 新增额外板级硬件 kill 信号支持。
- 新的远程诊断工具或 PC 端 UI。

## 需求（Requirements）

### MUST

- 启动期关键检查必须输出 `boot.stage:*`、`boot.check:*`、`boot.summary:*` 日志。
- 输入电源链路异常时必须保持 `IN_EN` 关闭，并停留在 fatal 自检页。
- 输入资格仅接受 `INA226.VBUS ≤ 28.0 V`；超过上限时必须报告 `PowerInOvervoltage` / `VIN OVP`，并保持 `IN_EN` 关闭。
- 运行期每个 `100 ms` 保护采样必须重新判定该上限；若 `INA226.VBUS > 28.0 V`，必须在下一保护采样周期内关闭并锁存 `IN_EN`，同时发布 `vin_on=false`，不得自动重开。
- 当前 V3 硬件下，前面板缺失时必须在有限恢复失败后标记 `Warn/FrontPanelOffline`，禁用前面板输入任务，并继续进入 dashboard/runtime。
- 当前直连 I²C 板型下，端口自检失败只记录诊断，不得单独阻断该路输出；只要总输入 `OK`，自检完成后统一放行 `EN1..EN4`。
- boot self-check 必须保留 `mux` 槽位，以兼容后续硬件版本恢复 `PCA9545A`。

### SHOULD

- 自检页在启动中显示进度，并在 degraded 场景展示失败摘要后再进入 dashboard。
- 自检页的系统面和端口面使用同一套状态/故障码口径。

### COULD

- 后续将 boot self-check 快照扩展为 runtime overlay 或更丰富的维护页。

## 功能与行为规格（Functional/Behavior Spec）

### Core flows

- 固件初始化时先建立显示与基础 GPIO，再进入 `Self-Check` 阶段。
- `Self-Check` 固定顺序为：I²C 拓扑 -> VIN/INA226 -> Front Panel -> Fan -> 4 路端口。
- 通过 `GateDecision` 决定是否放行 runtime task、front panel 和各端口。
- `BootOutcome=Fatal` 时常驻自检页；`BootOutcome=Degraded` 时展示摘要后进入 dashboard；`BootOutcome=Ok` 时直接切换 dashboard。

### Edge cases / errors

- 当前板型无 `PCA9545A`：记录 `boot.check: name=mux state=skip fault=-`，端口扫描继续进行。
- VIN 不可用或 PG 不良：标记系统项 `Fatal`，不进入端口初始化，不放行 runtime。
- `INA226.VBUS > 28.0 V`：标记系统项 `Fatal/PowerInOvervoltage`，启动日志、LCD 与硬件快照使用 `VIN OVP`，不放行 runtime。
- Front panel 离线：当前 V3 硬件下标记 `Warn/FrontPanelOffline`，只禁用 panel 功能。
- Front panel 离线诊断：固件必须记录 bus-clear 前后 SDA/SCL 电平、`0x21` 输入寄存器读取结果、ACK fallback、`front INT` 电平，以及 `0x20/0x44/0x70` peer device 在线矩阵。
- 单路端口若 `INA226`/`TMP112` 缺失：标记对应端口 `Err`，但只影响诊断与该路运行期测量，不阻断统一输出放行。
- 端口自检以“存在性与可诊断性优先”为准，不再依赖旧的 `SC8815/SW2303` 初始化链路。

## 接口契约（Interfaces & Contracts）

### 接口清单（Inventory）

| 接口（Name） | 类型（Kind） | 范围（Scope） | 变更（Change） | 契约文档（Contract Doc） | 负责人（Owner） | 使用方（Consumers） | 备注（Notes） |
| --- | --- | --- | --- | --- | --- | --- | --- |
| `boot_diag` 状态模型 | internal | internal | New | None (this SPEC) | firmware | boot flow / LCD boot page | 新增内部状态与门控口径 |
| `power_in::bootstrap_signal()` | internal | internal | New | None (this SPEC) | firmware | boot flow | 提供启动期电源探测结果 |

### 契约文档（按 Kind 拆分）

None

## 验收标准（Acceptance Criteria）

- Given 板子正常上电，When 固件启动，Then LCD 先显示自检页，串口输出 `boot.stage:*` 与 `boot.check:*`，最终输出 `boot.summary: outcome=OK|DEG` 并进入 dashboard。
- Given 当前直连 I²C 板型，When 固件启动，Then 日志记录 `boot.check: name=mux state=skip fault=-`，且端口扫描继续进行。
- Given 前面板 `TCA6408A` 缺失，When 当前 V3 硬件启动，Then 固件标记 `Warn/FrontPanelOffline`，禁用前面板输入任务，并继续进入 dashboard 与 runtime。
- Given MCU-only reset 后 `TCA6408A@0x21` 不响应，When front panel 自检失败，Then 日志包含 `i2c.front_probe:*`、`i2c.front_diag:*` 和分类结果，可区分 bus stuck、front TCA only offline、shared I2C offline or power。
- Given 单路输出模块缺少 `INA226` 或 `TMP112`，When 固件启动且总输入 `OK`，Then 该路记为 `Err`，但 `EN1..EN4` 仍在自检结束后统一放行。
- Given 输入电源资格失败或 PG 不良，When 固件启动，Then `IN_EN` 保持关闭且 LCD 常驻 fatal 自检页。
- Given `INA226.VBUS` 高于 `28.0 V`，When 固件启动，Then `IN_EN` 保持关闭，且启动日志、LCD 与硬件快照报告 `VIN OVP`。
- Given 输入已合规启动，When 运行期采样到 `INA226.VBUS > 28.0 V`，Then `IN_EN` 在 `100 ms` 内关闭并保持关闭、`vin_on=false`，硬件快照报告 `VIN OVP`。
- Given 当前验证基线中的通道 4 模块接入，When 固件启动，Then 端口 4 按 `INA226@0x43 + TMP112@0x4B` 识别并可报告 `boot.check: name=port4 state=ok fault=-`。

## 实现前置条件（Definition of Ready / Preconditions）

- 目标、非目标、范围与 fatal/degraded 判据已冻结。
- 关键内部接口与自检口径已在本 SPEC 确定。
- 验收标准覆盖正常启动、直连 I²C 拓扑、VIN 异常、front panel 离线、单路异常几种核心场景。

## 非功能性验收 / 质量门槛（Quality Gates）

### Testing

- Unit tests: None
- Integration tests: None
- E2E tests (if applicable): 真机串口日志与 LCD 行为验证至少 1 轮

### UI / Storybook (if applicable)

- Stories to add/update: None
- Visual regression baseline changes (if any): None

### Quality checks

- `cargo check`
- `cargo build --release`

## 文档更新（Docs to Update）

- `docs/software_design.md`: 同步 boot self-check、门控、fatal/degraded 口径。
- `docs/specs/README.md`: 增加本规格索引。

## 计划资产（Plan assets）

None

## Visual Evidence

PR: none

- LCD 自检页通过受控主机渲染验证；此规格不发布额外截图资源。

## 资产晋升（Asset promotion）

None

## 实现里程碑（Milestones / Delivery checklist）

- [x] M1: 落地 boot self-check 状态模型、阶段日志与门控框架
- [x] M2: 启动流程改为降级而非 panic，并补齐 VIN/topology/front panel/port 判定
- [x] M3: 落地 LCD boot self-check 摘要页与 degraded/fatal 切换行为
- [x] M4: 更新设计文档，并完成构建与真机验证证据

## 方案概述（Approach, high-level）

- 参考 `mains-aegis/docs/boot-self-test-flow.md` 的“默认只读探测 + 非紧急不乱改输出 + 紧急才阻断”方法，但只保留本仓库所需的最小实现。
- 用统一 `BootSelfCheckSnapshot` 驱动日志、自检页和启动后门控，避免每个模块各说各话。
- 用最小的两页轮转自检 UI 承载系统项和端口项，不新增复杂交互。
- 当前板型按直连共享 I²C 实现；后续若恢复 `PCA9545A`，在保留 `mux` 槽位的前提下切回真实 MUX 探测与门控。

## 风险 / 开放问题 / 假设（Risks, Open Questions, Assumptions）

- 风险：当前工程验证阶段并非所有可选硬件都会接入，因此端口 `Err` 需要结合开发笔记解释，不能直接等同于硬件故障。
- 需要决策的问题：None
- 假设（需主人确认）：当前可观测的 fatal 条件以输入电源不安全为主；单路输出模块缺失传感器按 degraded 处理；总输入 `OK` 时统一放行各路输出。

## 参考（References）

- `docs/software_design.md`
- `/Users/ivan/Projects/Ivan/mains-aegis/docs/boot-self-test-flow.md`

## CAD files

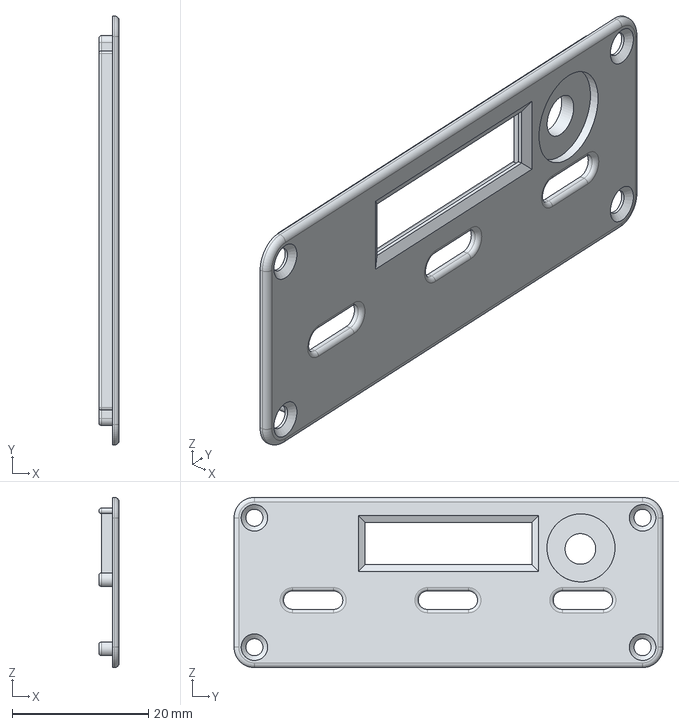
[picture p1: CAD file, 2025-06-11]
models/iso-usb-hub-with-pd-Front.step
3.00 x 63.0 x 25.0 mm

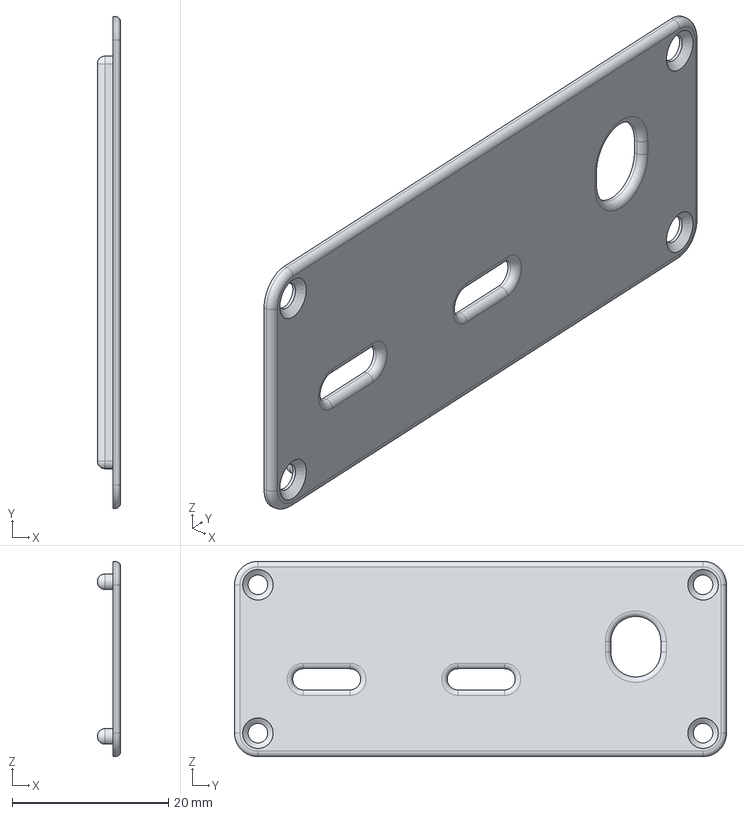
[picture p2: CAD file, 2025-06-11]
models/iso-usb-hub-with-pd-Back.step
3.00 x 63.0 x 25.0 mm

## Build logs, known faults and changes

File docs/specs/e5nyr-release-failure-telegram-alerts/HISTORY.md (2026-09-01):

# 发布失败 Telegram 告警历史

## 2026-07-07

- 新增 repo-local notifier wrapper，覆盖 Release、Development Release 与非 PR Site Publish 失败。
- 保留 `workflow_dispatch` smoke test 入口，并通过 `SHOUTRRR_URL` 调用旧的共享 Telegram reusable workflow。

## 2026-09-01

- 实时确认 Oidrune latest release `v0.1.14`，并将目标 pinned 到 `e48822f99c6402a753ed86557ea029754cbab20b`。
- 将失败与 smoke 两条调用迁移到 Oidrune `notify.yml`，改为传递 `outcome` 与 caller-generated `summary`。
- 补齐 caller 的 `id-token: write` 权限，移除旧 `github-workflows` target 与 `SHOUTRRR_URL` secret 传递，并保留 Site Publish 非 PR 过滤语义。
- 新增并接入 workflow contract test，覆盖 pinned SHA、summary、权限、过滤和 smoke 路径。
- 本次迁移通过 PR #40 交付；PR 的当前 head 以 GitHub live facts 为准。

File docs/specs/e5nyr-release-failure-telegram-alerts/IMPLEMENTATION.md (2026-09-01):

# 发布失败 Telegram 告警实现状态

## 当前覆盖

- `.github/workflows/notify-release-failure.yml` 继续监听 `Release`、`Development Release` 与 `Site Publish` 的完成事件，仅处理失败结果，并排除 PR 版 `Site Publish`。
- `notify_failure` 与 `smoke_test` 均调用 `IvanLi-CN/oidrune/.github/workflows/notify.yml@e48822f99c6402a753ed86557ea029754cbab20b`。
- 调用方声明 `id-token: write`，省略 `gateway_url` / `oidc_audience` 以使用 Oidrune 默认网关，并移除 `SHOUTRRR_URL` 传递。
- 两条路径都由调用方完整生成 summary，覆盖标题、项目、状态/结果、目标 SHA、run URL，并保留 workflow、ref、attempt、actor、event 等诊断字段。
- `scripts/test-notify-release-failure-contract.mjs` 覆盖 pinned target、旧目标/secret 清除、OIDC 权限、summary 字段和触发边界，并接入现有 `check.yml`。

## 验证口径

- 本地运行 Node workflow contract test 与 actionlint。
- 本地继续执行仓库约定的 `cargo check` 与 `cargo build --release`。
- 本次迁移不触发 `workflow_dispatch` smoke，不发送真实 Telegram/Oidrune 通知，也不修改 Oidrune 控制面。

## 剩余事项

- 手动 smoke 的真实链路验证仍需由 owner 在需要时显式触发。
- GitHub Pages Actions source 的 owner 侧设置仍是独立的外部配置，不属于本迁移。

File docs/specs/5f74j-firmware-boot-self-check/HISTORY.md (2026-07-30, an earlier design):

# 固件健壮化与开机自检历史

## 关键演进

- 固件启动从早期 `panic!` 改为统一 self-check、故障码、LCD 摘要页与门控决策。
- 当前硬件从旧的 I2C mux 结构演进为直连共享 I2C，总线拓扑检查保留 `mux` 槽位以兼容后续硬件。
- 实物验证发现 MCU-only reset 后，前面板 `TCA6408A@0x21` 可能保持离线；当前 V3 没有 MCU 可控 reset 或 power-cycle 路径，因此固件只能执行 I2C bus-clear 与有限探测。
- 为避免产品在当前硬件上卡在 `PANEL PEND`，V3 固件将前面板离线记录为 `Warn/FrontPanelOffline` 并继续 runtime；硬件缺陷已登记为 GitHub issue #18。
- 在 `/dev/cu.usbmodem2123101` 的实机复验中，输入资格阶段测得 `INA226.CURRENT ≈ 22–23 mA`；原先 `10 mA` 的启动空载阈值会把当前 V3 板误判成 `VIN OFF/FATAL`。阈值现已调整到 `30 mA`，以匹配当前 V3 基线并恢复 runtime/USB JSONL bring-up。
- 输入电压产品上限明确为 `28.0 V`。启动资格、运行期快照与自检诊断统一采用该严格边界；超过上限时以 `VIN OVP` 区分于一般 VIN 不可用或 PG 异常。
- 运行期输入状态原先会在成功启动后保持 `vin_on=true`，即使后续采样已超过上限；过压处理现改为每 `100 ms` 重新判定、关闭并锁存输入开关，同时发布 `vin_on=false`，确保保护状态、日志和快照一致。

## Legacy Source

- `docs/software_design.md`
- `docs/specs/5f74j-firmware-boot-self-check/SPEC.md`

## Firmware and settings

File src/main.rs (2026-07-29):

//! ESP32-S3 MVP Firmware
//!
//! Implements the MVP per docs/software_design.md:
//! - Boot init: time, GPIO, I2C, basic presence scans
//! - Direct I2C bus + per-port output-module sensor checks
//! - Front-panel TCA6408A (0x21) presence check
//! - Power input subsystem MVP: INA226-based input qualification and 10s status log

#![no_std]
#![no_main]

extern crate alloc;

use core::sync::atomic::{AtomicBool, AtomicI32, AtomicU8, Ordering};
use defmt::{info, warn};
use embassy_executor::Spawner;
use embassy_time::{with_timeout, Duration, Instant, Timer};
// Note: use fully-qualified trait calls for embedded-hal to avoid unused-import lints under clippy -D warnings
use esp_backtrace as _;
use esp_hal::analog::adc::{Adc, AdcConfig, Attenuation};
use esp_hal::efuse::Efuse;
use esp_hal::gpio::{DriveMode, Flex, Input, InputConfig, Level, Output, OutputConfig, Pull};
use esp_hal::i2c::master::{Config as I2cConfig, I2c};
use esp_hal::ledc::{LSGlobalClkSource, Ledc};
use esp_hal::spi::master::{Config as SpiConfig, Spi};
use esp_hal::spi::Mode as SpiMode;
use esp_hal::system;
use esp_hal::timer::timg::TimerGroup;
use esp_hal::usb_serial_jtag::UsbSerialJtag;
use esp_println as _;
// Shared I2C bus infrastructure
mod audio_logic;
mod boot_diag;
mod buzzer;
mod device_contract;
mod device_identity;
mod hardware_snapshot;
mod http_api_v1;
mod hub_sideband;
mod mdns;
mod network_runtime;
mod power_in;
mod power_limits;
mod usb_jsonl;
use embassy_embedded_hal::shared_bus::asynch::i2c::I2cDevice;
use embassy_sync::blocking_mutex::raw::CriticalSectionRawMutex;
use embassy_sync::channel::Receiver;
use embassy_sync::mutex::Mutex;
// use embassy_sync::signal::Signal; // not used on this branch
use static_cell::StaticCell;
mod fan;
mod front_panel;
mod provisioning;
mod runtime_control;
use boot_diag::{
    fault_label, outcome_label, state_label, BootFaultCode, BootOutcome, BootSelfCheckSnapshot,
    BootStage, GateDecision, SelfCheckItemState, SysCheck,
};
use hardware_snapshot as hwdiag;
use power_limits::{classify_voltage, voltage_in_range, VoltageRange};

// No global mutex in MVP

// INA226 is handled inside power_in task

use ina226_tp as ina226;
// Display driver
use embedded_graphics::{
    mono_font::{ascii::FONT_7X13_BOLD, MonoTextStyle},
    pixelcolor::Rgb565,
    prelude::*,
    primitives::{PrimitiveStyle, Rectangle},
    text::{Baseline, Text},
};
// esp-hal Output has inherent set_low/set_high; no trait import needed
use crate::audio_logic::{
    center_button_tone, choose_alarm, next_input_over_power, AlarmTone, PortAudioTracker, Tone,
};
use crate::device_contract::{
    HubSnapshot as UsbHubSnapshot, PortSnapshot as UsbPortSnapshot,
    PortTelemetryStatus as UsbPortTelemetryStatus, RuntimeSnapshot as UsbRuntimeSnapshot,
    WifiSnapshot as UsbWifiSnapshot, WifiState as UsbWifiState,
};
use crate::http_api_v1::ApiPendingAction;
use crate::runtime_control::{
    apply_port_action, apply_wifi_clear_snapshot, apply_wifi_set_snapshot, tick_replug_countdowns,
    PortControlAction, PortRuntimeState,
};
use embedded_hal_async::spi::{Operation as SpiOp, SpiBus as Eh1SpiBus, SpiDevice as Eh1SpiDevice};
use gc9d01::{Config as DisplayConfig, Orientation, Timer as Gc9d01Timer, GC9D01};
use provisioning::{
    clear_wifi_credentials, load_wifi_credentials, store_wifi_credentials, WifiCredentials,
};
use usb_jsonl::{UsbAction, UsbJsonlState};

esp_bootloader_esp_idf::esp_app_desc!();

// Provide a global timestamp for defmt logs (milliseconds since boot)
defmt::timestamp!("{=u64} ms", {
    esp_hal::time::Instant::now()
        .duration_since_epoch()
        .as_millis()
});

// Type alias for the async I2C bus and a global container to share it
type I2cBus = I2c<'static, esp_hal::Async>;
type SharedI2cBus = Mutex<CriticalSectionRawMutex, I2cBus>;
static SENSOR_I2C_BUS: StaticCell<SharedI2cBus> = StaticCell::new();
static HUB_I2C_BUS: StaticCell<SharedI2cBus> = StaticCell::new();
static mut SENSOR_I2C_BUS_REF: Option<&'static SharedI2cBus> = None;
static WIFI_CREDENTIALS_CACHE: Mutex<CriticalSectionRawMutex, Option<WifiCredentials>> =
    Mutex::new(None);
// Latch channel readiness for UI without blocking on Signal::wait
static CH_RDY: [AtomicBool; 4] = [
    AtomicBool::new(false),
    AtomicBool::new(false),
    AtomicBool::new(false),
    AtomicBool::new(false),
];
// Scan completion flag per channel (true once initial scan concludes, even if offline)
static CH_SCAN_DONE: [AtomicBool; 4] = [
    AtomicBool::new(false),
    AtomicBool::new(false),
    AtomicBool::new(false),
    AtomicBool::new(false),
];

// （已按要求撤销 TCA6408A 虚拟 GPIO 实现）

// Global target state: open/closed (intent)
#[derive(Copy, Clone, Eq, PartialEq)]
#[repr(u8)]
enum PowerSwitchTarget {
    Open,
    Closed,
}

// Global intent per docs/software_design.md 0.1
static PWR_SW_TARGET: AtomicU8 = AtomicU8::new(PowerSwitchTarget::Open as u8);
static POWER_LATEST_VIN_MV: AtomicI32 = AtomicI32::new(0);
static POWER_LATEST_PG_GOOD: AtomicBool = AtomicBool::new(false);
static POWER_LATEST_READY: AtomicBool = AtomicBool::new(false);
static POWER_LATEST_FAULT: AtomicU8 = AtomicU8::new(3);

// No shared snapshot; status task logs directly

// I2C shared in init and reused by async tasks / runtime sampling.

// Board-specific pins per docs/esp32-s3fh4r2_gpio_assignment_guide.md
#[allow(dead_code)]
const PIN_I2C_SDA: u8 = 8;
#[allow(dead_code)]
const PIN_I2C_SCL: u8 = 9;
#[allow(dead_code)]
const PIN_HUB_I2C_SDA: u8 = 14;
#[allow(dead_code)]
const PIN_HUB_I2C_SCL: u8 = 13;
#[allow(dead_code)]
const PIN_I2C_INT: u8 = 16;
#[allow(dead_code)]
const PIN_I2C_RESET: u8 = 35; // mainboard active-low reset net; front-panel TCA reset is local pull-up

#[allow(dead_code)]
const PIN_IN_CE: u8 = 41; // high = force TPS2490 EN low/off, low = allow/on
#[allow(dead_code)]
const PIN_IN_PG: u8 = 42; // TPS2490 PG (open drain, high = good)

#[allow(dead_code)]
const PIN_USB_V1OK: u8 = 21; // ISOUSB211 side-1 power OK (high = upstream side powered)
#[allow(dead_code)]
const PIN_BUZZER: u8 = 7; // passive buzzer via LEDC PWM output, idle low

// Output-module enable lines (V3): EN high = module enabled
#[allow(dead_code)]
const PIN_EN1: u8 = 17;
#[allow(dead_code)]
const PIN_EN2: u8 = 18;
#[allow(dead_code)]
const PIN_EN3: u8 = 39;
#[allow(dead_code)]
const PIN_EN4: u8 = 40;

// INA226 shunt value (ohms) from docs: 5 mΩ
const SHUNT_RESISTANCE_OHMS: f32 = 0.005;

// Qualification thresholds (see docs/software_design.md §2)
// 开发阶段临时放宽：将 VIN 下限改为 4.5V 以便在 5V 供电/风扇台架下进行功能验证；
// 量产应恢复到 9.0V 以避免 5–8V 区间误判上电（请在合入前复位该值）。
const VIN_MIN_V: f32 = 4.5;
const VIN_MAX_V: f32 = 28.0;
// Current V3 bench baseline draws about 22-23 mA before IN_EN closes.
// Keep a small margin above that so qualification reflects real hardware,
// while still rejecting clearly abnormal startup load.
const I_IDLE_MAX_A: f32 = 0.030; // 30 mA
const INA226_SHUNT_LSB_V: f32 = 2.5e-6;

// V3 IP6557 modules are strapped to unique addresses. OUT1/OUT2 share SDA0/SCL0
// with hub sideband; OUT3/OUT4 share SDA1/SCL1 with front/input sensors.
const MODULE_INA226_ADDRS: [u8; 4] = [0x40, 0x41, 0x42, 0x43];
const MODULE_TMP112_ADDRS: [u8; 4] = [0x48, 0x49, 0x4A, 0x4B];
const MODULE_SENSOR_RETRY_MS: u64 = 50;
const MODULE_SENSOR_RETRIES: u8 = 6;

// ===== Display pin mapping (V3 netlist) =====
// SPI2 SCLK/MOSI to panel; MISO unused. Latest mainboard routes GPIO13/14 to hub I2C.
// BLK drives a panel-side P-channel gate and is therefore active-low.
const PIN_LCD_SCLK: u8 = 12;
const PIN_LCD_MOSI: u8 = 11;
const PIN_LCD_DC: u8 = 10;
const PIN_LCD_BLK_GPIO: u8 = 15;

const TCA6408_ADDR: u8 = 0x21;
const INPUT_INA226_ADDR: u8 = 0x44;
const PCA9545_ADDR: u8 = 0x70;
const I2C_RECOVERY_CLOCKS: u8 = 18;
const FRONT_PANEL_BOOT_PROBE_ATTEMPTS: u8 = 3;
const PORT_OCP_LOW_VBUS_MV: u32 = 3000;
const PORT_OCP_LOW_VBUS_MIN_CURRENT_MA: u32 = 100;
const PORT_OCP_HIGH_CURRENT_MA: u32 = 5300;
const PORT_OCP_RELEASE_SAFE_SAMPLES: u8 = 4;
const USB_REPLUG_HOLDOFF_TICKS: u8 = 2;
const RUNTIME_SAMPLE_PERIOD_MS: u64 = 500;
const RUNTIME_IDLE_SLICE_MS: u64 = 20;
const DIAG_SNAPSHOT_PERIOD_TICKS: u32 = 20;
const FRONT_DIAG_FRONT_MASK: u8 = 1 << 0;
const FRONT_DIAG_HUB_MASK: u8 = 1 << 1;
const FRONT_DIAG_INPUT_INA_MASK: u8 = 1 << 2;
const FRONT_DIAG_MUX_MASK: u8 = 1 << 3;

#[derive(Copy, Clone)]
struct I2cRecoveryReport {
    sda_released: bool,
    scl_released: bool,
    sda_initial: bool,
    scl_initial: bool,
    sda_final: bool,
    scl_final: bool,
}

fn module_addr_pair(ch: u8) -> (u8, u8) {
    let idx = (ch & 0x03) as usize;
    (MODULE_INA226_ADDRS[idx], MODULE_TMP112_ADDRS[idx])
}

fn module_i2c_bus(
    ch: u8,
    sensor_bus: &'static SharedI2cBus,
    hub_bus: &'static SharedI2cBus,
) -> (&'static SharedI2cBus, &'static str) {
    if ch < 2 {
        (hub_bus, "SDA0/SCL0")
    } else {
        (sensor_bus, "SDA1/SCL1")
    }
}

async fn i2c_ack_probe<I2C: embedded_hal_async::i2c::I2c>(
    i2c: &mut I2C,
    addr: u8,
) -> (bool, &'static str) {
    let mut b = [0u8; 2];
    if embedded_hal_async::i2c::I2c::write_read(i2c, addr, &[0x00], &mut b)
        .await
        .is_ok()
    {
        return (true, "wr_rd");
    }
    if embedded_hal_async::i2c::I2c::read(i2c, addr, &mut b)
        .await
        .is_ok()
    {
        return (true, "rd");
    }
    if embedded_hal_async::i2c::I2c::write(i2c, addr, &[])
        .await
        .is_ok()
    {
        return (true, "addr");
    }
    (false, "no")
}
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
async fn main(spawner: Spawner) {
    esp_alloc::heap_allocator!(size: 64 * 1024);

    let p = esp_hal::init(esp_hal::Config::default());
    let reset_reason = system::reset_reason();
    let usb_mac = Efuse::read_base_mac_address();
    let mut usb_serial = UsbSerialJtag::new(p.USB_DEVICE);
    let mut usb_jsonl = UsbJsonlState::<1024>::new();
    info!("app.start");

    // Initialize the embassy time driver
    let timg0 = TimerGroup::new(p.TIMG0);
    esp_hal_embassy::init(timg0.timer0);
    info!("init.time: embassy-timer=ok");

    // GPIO prepare
    // Mainboard RESET# is MCU-driven and also releases the front-panel TCA6408A.
    // The LCD panel RES/CS pins are controlled by that front-panel TCA after it is online.
    let mut board_reset = Output::new(
        p.GPIO35,
        Level::Low,
        esp_hal::gpio::OutputConfig::default().with_drive_mode(DriveMode::PushPull),
    );
    info!("main.reset: gpio=GPIO35 mode=push-pull pulse=10ms release_wait=50ms");
    Timer::after(Duration::from_millis(10)).await;
    board_reset.set_high();
    Timer::after(Duration::from_millis(50)).await;
    let board_reset_released_high = board_reset.is_set_high();

    // M24C64 #WC is active high. Drive it low before any provisioning access so
    // writes are not silently ignored while reads still work.
    let _rom_wc = Output::new(
        p.GPIO37,
        Level::Low,
        esp_hal::gpio::OutputConfig::default().with_drive_mode(DriveMode::PushPull),
    );
    // CH442E selects S2B/S2C when IN is high. S2 is the MCU SDA0/SCL0 side,
    // while S1 is the CH335F/HUB_LED3 side, so keep EEPROM routed to firmware.
    let _rom_route = Output::new(
        p.GPIO38,
        Level::High,
        esp_hal::gpio::OutputConfig::default().with_drive_mode(DriveMode::PushPull),
    );

    // IN_CE default off: high turns on the NMOS that pulls TPS2490 EN low.
    let in_ce = Output::new(
        p.GPIO41,
        Level::High,
        esp_hal::gpio::OutputConfig::default(),
    );
    // PG input
    let in_pg = Input::new(
        p.GPIO42,
        esp_hal::gpio::InputConfig::default().with_pull(Pull::Up),
    );
    let usb_v1ok = Input::new(
        p.GPIO21,
        esp_hal::gpio::InputConfig::default().with_pull(Pull::Up),
    );
    info!(
        "hub.upstream: v1ok={} gpio=GPIO{}",
        if usb_v1ok.is_high() { "high" } else { "low" },
        PIN_USB_V1OK
    );
    let mut vin_adc_config = AdcConfig::new();
    let vin_adc_pin: power_in::VinAdcPin =
        vin_adc_config.enable_pin_with_cal(p.GPIO4, Attenuation::_11dB);
    let vin_adc = Adc::new(p.ADC1, vin_adc_config);

    let front_int_pin = Input::new(
        p.GPIO16,
        esp_hal::gpio::InputConfig::default().with_pull(Pull::Up),
    );

    // EN lines default disabled (drive low => module disabled)
    let mut port_enables = [
        Output::new(p.GPIO17, Level::Low, esp_hal::gpio::OutputConfig::default()),
        Output::new(p.GPIO18, Level::Low, esp_hal::gpio::OutputConfig::default()),
        Output::new(p.GPIO39, Level::Low, esp_hal::gpio::OutputConfig::default()),
        Output::new(p.GPIO40, Level::Low, esp_hal::gpio::OutputConfig::default()),
    ];
    for port_enable in port_enables.iter_mut() {
        port_enable.set_low();
    }

    let mut ledc = Ledc::new(p.LEDC);
    ledc.set_global_slow_clock(LSGlobalClkSource::APBClk);

    buzzer::spawn(&spawner, p.GPIO7).expect("spawn buzzer task");

    info!("init.hw: chip=ESP32-S3 sensor_i2c=sdaGPIO8/sclGPIO9 hub_i2c=sdaGPIO14/sclGPIO13 rom_wc=GPIO37-low rom_route=GPIO38-high");

    // Publish power-on intent first (only intent; actual switch controlled after qualification)
    PWR_SW_TARGET.store(PowerSwitchTarget::Closed as u8, Ordering::Relaxed);

    // Recover a possible half-finished sensor/front-panel I2C transaction left by MCU-only resets.
    let (i2c_sda, i2c_scl, i2c_recovery) = recover_i2c_bus(p.GPIO8, p.GPIO9).await;
    // Initialize I2C0 on SDA1/SCL1 for input INA226, front panel, and OUT3/OUT4 sensors.
    let i2c_hw = I2c::new(p.I2C0, I2cConfig::default())
        .unwrap()
        .with_sda(i2c_sda)
        .with_scl(i2c_scl)
        .into_async();
    let bus = SENSOR_I2C_BUS.init(Mutex::new(i2c_hw));

    // Initialize I2C1 on SDA0/SCL0 for the mainboard CH335F sideband expander and OUT1/OUT2 sensors.
    let hub_i2c_hw = I2c::new(p.I2C1, I2cConfig::default())
        .unwrap()
        .with_sda(p.GPIO14)
        .with_scl(p.GPIO13)
        .into_async();
    let hub_bus = HUB_I2C_BUS.init(Mutex::new(hub_i2c_hw));

    info!("lcd.ctrl: cs=front-tca-p6 rst=front-tca-p5 board_reset=GPIO35");

    let mut display_control_state = front_panel::init_display_control(bus).await;
    match display_control_state {
        Ok(state) => info!(
            "lcd.ctrl: front-tca configured output=0x{:02X} config=0x{:02X} cs_p6=low_output res_p5=high_output",
            state.output, state.config
        ),
        Err(_) => warn!("lcd.ctrl: front-tca display control failed"),
    }

    // Setup SPI2 and display. Latest mainboard exposes DC/MOSI/SCLK/BLK directly;
    // LCD CS/RES are driven by the front-panel TCA6408A P6/P5.
    let spi_bus = Spi::new(
        p.SPI2,
        SpiConfig::default()
            .with_frequency(esp_hal::time::Rate::from_hz(10_000_000))
            .with_mode(SpiMode::_0),
    )
    .unwrap()
    .with_sck(match PIN_LCD_SCLK {
        12 => p.GPIO12,
        _ => p.GPIO12,
    })
    .with_mosi(match PIN_LCD_MOSI {
        11 => p.GPIO11,
        _ => p.GPIO11,
    })
    .into_async();

    let dc = match PIN_LCD_DC {
        10 => Output::new(p.GPIO10, Level::Low, esp_hal::gpio::OutputConfig::default()),
        _ => Output::new(p.GPIO10, Level::Low, esp_hal::gpio::OutputConfig::default()),
    };
    // Backlight enable is active-low through the panel-side P-MOS gate.
    let mut blk = match PIN_LCD_BLK_GPIO {
        15 => Output::new(p.GPIO15, Level::Low, esp_hal::gpio::OutputConfig::default()),
        _ => Output::new(p.GPIO15, Level::Low, esp_hal::gpio::OutputConfig::default()),
    };
    blk.set_low();

    const LOGICAL_W: usize = 160;
    const LOGICAL_H: usize = 50;
    let mut fb_buf: [Rgb565; LOGICAL_W * LOGICAL_H] = [Rgb565::BLACK; LOGICAL_W * LOGICAL_H];
    let fb: &mut [Rgb565] = &mut fb_buf;

    let spi_dev = SimpleSpiDev {
        bus: spi_bus,
        cs: None,
    };
    let cfg = DisplayConfig {
        width: LOGICAL_W as u16,
        height: LOGICAL_H as u16,
        orientation: Orientation::LandscapeSwapped,
        rgb: false,
        inverted: false,
        dx: 15,
        dy: 0,
    };
    let rst = NoopPin;
    let mut disp: GC9D01<_, _, _, DisplayTimer> = GC9D01::new(cfg, spi_dev, dc, rst, fb);
    info!("lcd.init: start panel_160x50 mode (cs=front-tca-p6 rst=front-tca-p5 landscape-swapped)");
    if let Err(_e) = disp.init().await {
        warn!("lcd.init: failed (fallback)");
    } else {
        info!("lcd.init: panel ready");
    }
    if let Ok(state) = display_control_state {
        info!(
            "lcd.ctrl: verified output=0x{:02X} config=0x{:02X} cs_p6=low_output res_p5=high_output",
            state.output, state.config
        );
    }
    info!(
        "main.reset: release_level={} reset_reason={}",
        if board_reset_released_high {
            "high"
        } else {
            "low"
        },
        reset_reason_label(reset_reason)
    );

    let mut boot_snapshot = BootSelfCheckSnapshot::new();
    let mut module_probes = [hwdiag::PortProbe::skipped(); 4];
    let mut diag_sequence: u32 = 0;
    let mut latest_diag_snapshot = heapless::String::<12288>::new();
    let reset_reason_name = reset_reason_label(reset_reason);
    let i2c_diag = hwdiag::I2cSnapshot {
        topology: "dual_shared_bus",
        mux_state: hwdiag::NodeState::Skipped,
        mux_address: PCA9545_ADDR,
        recovery_clocks: I2C_RECOVERY_CLOCKS,
        reset_released_high: board_reset_released_high,
    };
    boot_snapshot.set_stage(BootStage::SelfCheck);
    info!("boot.stage: stage=self-check");
    flush_boot_self_check(&mut disp, &boot_snapshot, false).await;

    // Record global bus reference for channel views.
    unsafe {
        SENSOR_I2C_BUS_REF = Some(bus);
    }

    info!("i2c.topo: direct shared bus; mux probe skipped");
    info!("boot.check: name=mux state=skip fault=-");
    boot_snapshot.set_sys(
        SysCheck::Mux,
        SelfCheckItemState::Skipped,
        BootFaultCode::None,
    );
    flush_boot_self_check(&mut disp, &boot_snapshot, false).await;
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

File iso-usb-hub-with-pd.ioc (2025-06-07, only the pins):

Mcu.UserName=STM32G431C8Ux
PA10.Signal=SPI2_MISO
PA11.Signal=USB_DM
PA12.Signal=USB_DP
PA13.Signal=SYS_JTMS-SWDIO
PA14.Signal=SYS_JTCK-SWCLK
PA15.Signal=I2C1_SCL
PA4.Signal=SPI1_NSS
PA7.Signal=SPI1_MOSI
PA8.GPIO_Label=TIM1_CH1_BLK
PA8.Signal=S_TIM1_CH1
PB1.GPIO_Label=BTN2
PB1.Signal=GPIO_Input
PB12.Signal=SPI2_NSS
PB13.Signal=SPI2_SCK
PB15.Signal=SPI2_MOSI
PB2.GPIO_Label=BTN3
PB2.Signal=GPIO_Input
PB3.Signal=SPI1_SCK
PB5.Signal=I2C1_SMBA
PB7.Signal=I2C1_SDA
PC6.GPIO_Label=TIM3_CH1_BUZZER
PC6.Signal=S_TIM3_CH1

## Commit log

2025-06-07 feat: Initial project setup and display test
    Add basic project structure, build configuration for STM32G431C8U6, and display driver submodule.
    Include a simple color loop test for the GC9D01 display.
2025-06-09 feat(display): Implement dashboard and custom font rendering
    Introduce new module with dashboard and custom font rendering capabilities.
    Integrate the display driver.
    Configure display dimensions, orientation, and SPI frequency.
    Set up heap allocator using for dynamic memory.
    Update submodule to include recent fixes.
    [dashboard.rs, main.rs]
2025-06-09 feat(data-acquisition): Integrate INA226 sensors and refactor dashboard
    Integrate INA226 sensor driver for power monitoring.
    Initialize I2C1 bus and three INA226 sensors (0x40, 0x41, 0x44).
    Refactor Dashboard struct and update logic to handle per-port voltage, current, and power data.
    Update display drawing to show data for each of the 3 ports.
2025-06-10 feat(display): Update dashboard display logic and refresh interval\n\nAdd new colors (orange, blue) and update the color logic for displaying voltage, current, and power based on their values.\nChang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
2025-06-11 feat(models): Add 3D printable front and back cover parts
    Exported front and back parts of the FreeCAD model to STEP format for 3D printing.
    [iso-usb-hub-with-pd-Back.step, iso-usb-hub-with-pd-Front.step]
2026-07-29 fix(power): allow 28v input limit
    Report input overvoltage as VIN OVP during boot diagnostics.
    [main.rs, power_in.rs]
2026-07-30 fix(power): latch runtime overvoltage shutdown
    [power_in.rs]
